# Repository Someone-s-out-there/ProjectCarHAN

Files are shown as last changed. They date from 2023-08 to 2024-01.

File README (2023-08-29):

# README

## Links

[drive](https://drive.google.com/drive/folders/1EaNdhbWhvMzq_1hj-SwhNryWp-9N5PZe?usp=sharing)

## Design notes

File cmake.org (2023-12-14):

#+AUTHOR: Sjoerd van de Wege
#+PROPERTY: header-args :tangle CMakeLists.txt
#+auto_tangle: t

* TABLE OF CONTENTS :toc:
- [[#set-cmake-version-and-project-name][set cmake version and project name]]
- [[#mcu-specifics][MCU Specifics]]
- [[#fuses][FUSES]]
- [[#toolchain][TOOLCHAIN]]
- [[#compile-flags-and-definitions][compile flags and definitions]]
  - [[#compile-defines][compile defines]]
  - [[#set--mmcu-for-both-the-compiler-and-linker][set -mmcu for both the compiler and linker]]
- [[#collect-all-source-files][collect all source files]]
  - [[#needs-to-be-turned-in-to-the-correct-directories-and-stuff][needs to be turned in to the correct directories and stuff]]
- [[#creating-the-executable-and-other-targets][creating the executable and other targets]]

* set cmake version and project name
target a relatively old version of Cmake
and set the name of the project and the outputfile to RobotCar

#+begin_src cmake

cmake_minimum_required(VERSION 3.11)
project("RobotCar")
set(PRODUCT_NAME "RobotCar")
set(CMAKE_EXPORT_COMPILE_COMMANDS 1)

#+end_src

* MCU Specifics
set the variables for the clock speed of the MCU as well as the chip used
also sets the programmer used to program the chip with avrdude

#+begin_src cmake
set(F_CPU 16000000UL) # set clock speed to 16 MHZ
set(MCU atmega328p) # set chip identity full list at (https://gcc.gnu.org/onlinedocs/gcc/AVR-Options.html)
set(PROG_TYPE xplainedmini) # set programming device

#+end_src

* FUSES 
here we're setting the fuses for the avr chip
the following calculator can be used: http://eleccelerator.com/fusecalc/fusecalc.php?chip=atmega328p
#+begin_src cmake
set(E_FUSE 0xfd)
set(H_FUSE 0xda)
set(L_FUSE 0xfd)
set(LOCK_BIT 0xff)

#+end_src

* TOOLCHAIN
sets the toolchain to be the avr-gcc toolchain
#+begin_src cmake
set(CMAKE_SYSTEM_NAME Generic)
set(CMAKE_CXX_COMPILER avr-g++)
set(CMAKE_C_COMPILER avr-gcc)
set(CMAKE_ASM_COMPILER avr-gcc)

#+end_src

* compile flags and definitions

** compile defines
#+begin_src cmake

add_definitions(
    -DF_CPU=${F_CPU}
)

#+end_src

** set -mmcu for both the compiler and linker
__attribute__ ((fallthrough)); can be used to get rid of fallthrough warnings in switch case statements
#+begin_src cmake

set(CMAKE_EXE_LINKER_FLAGS -mmcu=${MCU})

add_compile_options(
    -mmcu=${MCU} # MCU
    -std=c11 # C11 standard
    -Os # optimize
    -Wall # enable warnings
    -Wextra
    -Wundef
    -Wunused-macros
    -Wnonnull
    -Wimplicit-fallthrough
    -Wmisleading-indentation
    -Wswitch-default
    -Wunused-parameter
    -Wshadow
    -Wparentheses
    -Wpacked
    -Wpadded
    -Winline
    -pedantic
    -Wstrict-prototypes
    -Wl,--relax,--gc-sections
    -funsigned-char # a few optimizations
    -funsigned-bitfields
    -fpack-struct
    -fshort-enums
)

#+end_src

* collect all source files
collects all source files for the project
** TODO needs to be turned in to the correct directories and stuff
#+begin_src cmake

file(GLOB_RECURSE SRC_FILES CONFIGURE_DEPENDS "*c")
file(GLOB_RECURSE REMOVE_CMAKE "build/*" "extern/*" )
list(REMOVE_ITEM SRC_FILES ${REMOVE_CMAKE})
include_directories("/home/sjoerd/opt/avr/avr/include")

#+end_src

* creating the executable and other targets

#+begin_src cmake

add_executable(${PRODUCT_NAME} ${SRC_FILES})
# Rename the output to .elf as we will create multiple files
set_target_properties(${PRODUCT_NAME} PROPERTIES OUTPUT_NAME ${PRODUCT_NAME}.elf)

# Strip binary for upload
add_custom_target(strip ALL avr-strip ${PRODUCT_NAME}.elf DEPENDS ${PRODUCT_NAME})

# Transform binary into hex file, we ignore the eeprom segments in the step
add_custom_target(hex ALL avr-objcopy -R .eeprom -O ihex ${PRODUCT_NAME}.elf ${PRODUCT_NAME}.hex DEPENDS strip)
# Transform binary into hex file, this is the eeprom part (empty if you don't
# use eeprom static variables)
add_custom_target(eeprom avr-objcopy -j .eeprom  --set-section-flags=.eeprom="alloc,load"  --change-section-lma .eeprom=0 -O ihex ${PRODUCT_NAME}.elf ${PRODUCT_NAME}.eep DEPENDS strip)

# Upload the firmware with avrdude
add_custom_target(upload avrdude  -c ${PROG_TYPE} -p ${MCU} -U flash:w:${PRODUCT_NAME}.hex DEPENDS hex)

# Upload the eeprom with avrdude
# add_custom_target(upload_eeprom avrdude -c ${PROG_TYPE} -p ${MCU}  -U eeprom:w:${PRODUCT_NAME}.eep DEPENDS eeprom)

# Burn fuses
add_custom_target(fuses avrdude -c ${PROG_TYPE} -p ${MCU}  -U lfuse:w:${L_FUSE}:m -U hfuse:w:${H_FUSE}:m -U efuse:w:${E_FUSE}:m -U lock:w:${LOCK_BIT}:m )

# Clean extra files
set_directory_properties(PROPERTIES ADDITIONAL_MAKE_CLEAN_FILES "${PRODUCT_NAME}.hex;${PRODUCT_NAME}.eeprom;${PRODUCT_NAME}.lst")

#+end_src

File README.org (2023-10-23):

#+TITLE: README
#+AUTHOR: Sjoerd van de Wege
#+DESCRIPTION
#+STARTUP: showeverything
#+OPTIONS: toc:2

*  README

Here in this Repository is the code for robotcar for both the first and the second period. for the first period the car was programmed in Arduino.
now for the second period the car will be programmed in C using avr-libc with Atmel Studio 7.

** compiling
the program can be compiled using Atmel Studio 7, or using commandline utilities with the make / cmake files.
** flashing and uploading
the program can be flashed to the chip using Atmel Studio 7's programming tool.
If desired Avrdude can also be used from the commandline or using the (c)make build system
#+begin_src bash
avrdude -pm328p -c xplainedmini -U flash:w:{FILE}
#+end_src

** Links

[drive](https://drive.google.com/drive/folders/1EaNdhbWhvMzq_1hj-SwhNryWp-9N5PZe?usp=sharing)
[Atmel Studio](https://www.microchip.com/en-us/tools-resources/develop/microchip-studio)

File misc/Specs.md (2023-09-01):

# Specs

## Questions
    1. wat voor een object ontwijken / in welke omstandigheden
        a: statish behalve auto's
            op autonome mode met 4 auto zonder contact.

    2. wat is de kleur van de lijn 
        a:zwarte lijn op ondergrond van lokaal licht
    3. breedte van de lijn 
        a: isolatie tape
    4. afstand tot de voorganger 
        a: iets 30ish cm
        stop afstand.

    5. wat voor een remote controll
        a: draadloos maakt niet uit

    6  wat voor een display
        :a display o de auto 
        6.1 eenheid voor snelheid (indien geen antwoord m/s)
            a: m/s
        6.2 tijds formaat 
            a:uur minuut seconde
    7. een menu op wat? (scherm met knoppen, telefoon (bt/wifi)
        a:op auto met knoppen 

    8. reflector achter
        8.1 kleur reflector
        8.2 groote reflector
        a: ligt aan de groepjes

    9. voorkeur voor kleur led voor richting
        a: mooiste oranje, makkelijste rood

documenten als groep
voorelkaar een bijdrage factora
eurocicuits

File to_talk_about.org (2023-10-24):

#+TITLE: to talk about
#+AUTHOR: Sjoerd van de Wege
#+DESCRIPTION
#+STARTUP: showeverything

* to talk about

** review last period
*** wat ging goed
*** wat ging niet goed
** hoe verder
*** nieuwe folder structuur
*** correct gebruik git
*** 1 project to rule them all. al geconfigured met alle waarschuwingen.
*** code moet ge reviewed worden voor dat er code ge merged word naar de main of dev branch
*** structuur van project is nu in basis al gelegd.
**** de basis van het project bestaat
**** overleggen over hoe en wat qua folders en structuur voor de sensoren en actoren.

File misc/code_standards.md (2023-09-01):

# Standards

<!--toc:start-->
- [Standards](#standards)
  - [software standards](#software-standards)
    - [Source Bestanden](#source-bestanden)
      - [Source Comment](#source-comment)
      - [Headers](#headers)
      - [Macros](#macros)
    - [HEADER Bestanden](#header-bestanden)
      - [Header Comment](#header-comment)
      - [public Macros](#public-macros)
      - [public types](#public-types)
      - [public functions](#public-functions)
        - [private functions](#private-functions)
  - [hardware standards](#hardware-standards)
<!--toc:end-->

## software standards
de onderstaande file layout staat elk deel uit gewerkt in de eigen paragraaf
    File Layout(.c bestanden)
        Block comment (/*...*/)
        Headers
        Macros
        Types
        Function declarations:
            including variable names
            Group/order in Logical manner 
        Global variables
        Function definition
            same order as declaration
        main (if applicable)
    File Layout(.h bestanden)
        Block comment
        header includes
        public macros
        public types
        public functions

### Source Bestanden
#### Source Comment 
de block comment (/*...*/) bevat een beschrijving van
waar voor het bestand is. deze geeft ook aan door wie het gemaakt is,
waneer het gemaakt is. dit geldt iets minder voor de arduino ide, maar
in periode 2 is dit relevant gezien er voor alles een driver gemaakt
moet worden.

#### Headers 
de included headers gesplit in 2 secties. een sectie met
compiler provided includes (#include <...>) en een sectie voor "user"
includes(#include "..."). hiermee wordt bedoeld door ons geschreven libraries voor 
de sensoren en actoren. 

#### Macros
Macros is alles dat met #define gedefinieerd wordt. Deze macros worden
door de preprocessor vervangen door de waarde die ze dragen met een
simple text subsistutie.

### HEADER Bestanden
#### Header Comment 
de block comment (/*...*/) bevat een beschrijving van
waar voor het bestand is. deze geeft ook aan door wie het gemaakt is,
waneer het gemaakt is. dit geldt iets minder voor de arduino ide, maar
in periode 2 is dit relevant gezien er voor alles een driver gemaakt
moet worden.

#### public Macros
deze macros zijn meestal algemeene macros die ook voor andere drivers
nodig kunnen zijn. dit zijn niet alle macros door de macros te
splitsen kan je voorkomen dat je 2 macros hebt die dezelfde naam
hebben. 

#### public types 
hier eventueel de types definieeren die als parameter of als return
type zijn voor functies. 

#### public functions
de public functions dienen als toegang tot de code in de rest van het
source bestand deze zijn roepen meestal interne functies aan die niet
public zijn. dit zorgt er ook voor dat de code completion van de ide's
niet vol raakt met funcites die nooit gebruikt.

##### private functions
de functies in een C source bestand die niet vanaf een ander bestand
aangeroepen  hoeven te worden kunnen het beste gedefinieerd worden als
`static returntype func(param);` boven in het .c bestand. het static
keyword zorgt er voor dat de functie alleen beschik baar is in de .c
file.

## hardware standards
    1. alle dip chips in sockets.

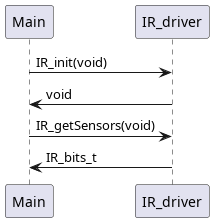
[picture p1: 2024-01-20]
uml/sensor/infrarood.png

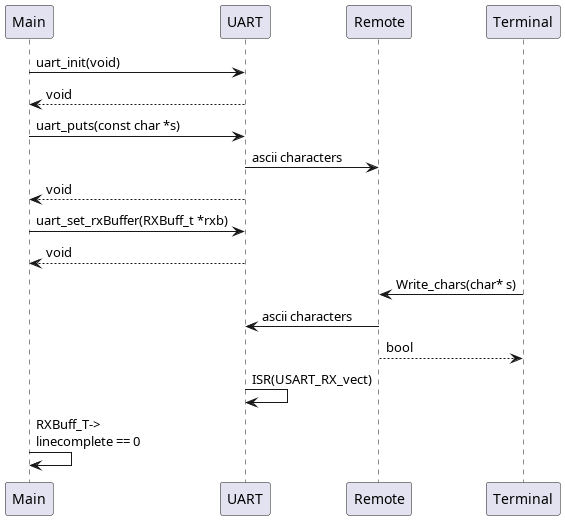
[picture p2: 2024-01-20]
uml/communication.png

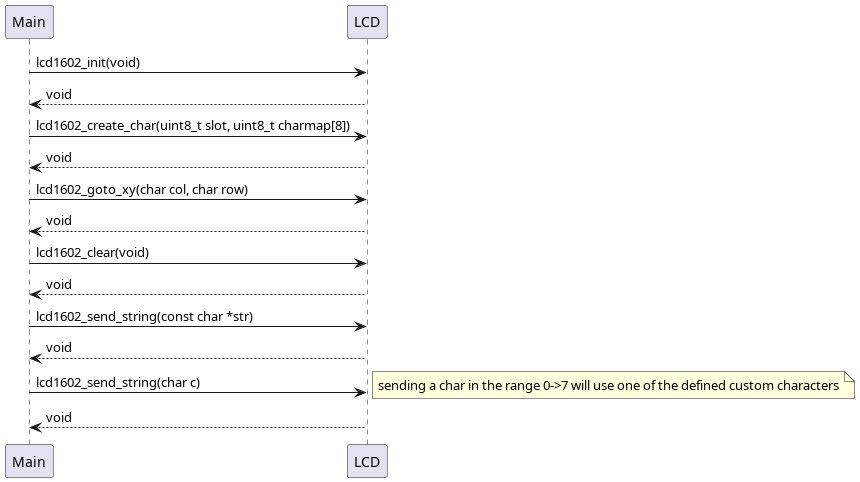
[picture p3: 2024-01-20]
uml/actor/display.png

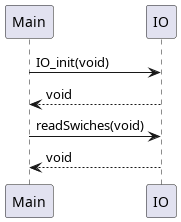
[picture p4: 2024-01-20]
uml/sensor/Switch.png

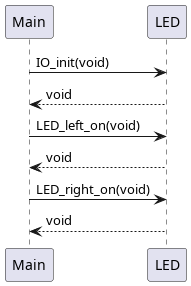
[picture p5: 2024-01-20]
uml/actor/led.png

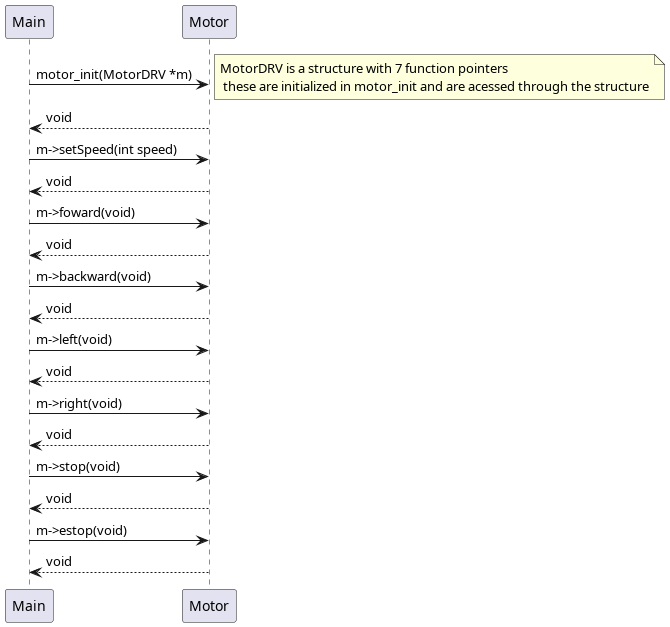
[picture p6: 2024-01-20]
uml/actor/motor.png

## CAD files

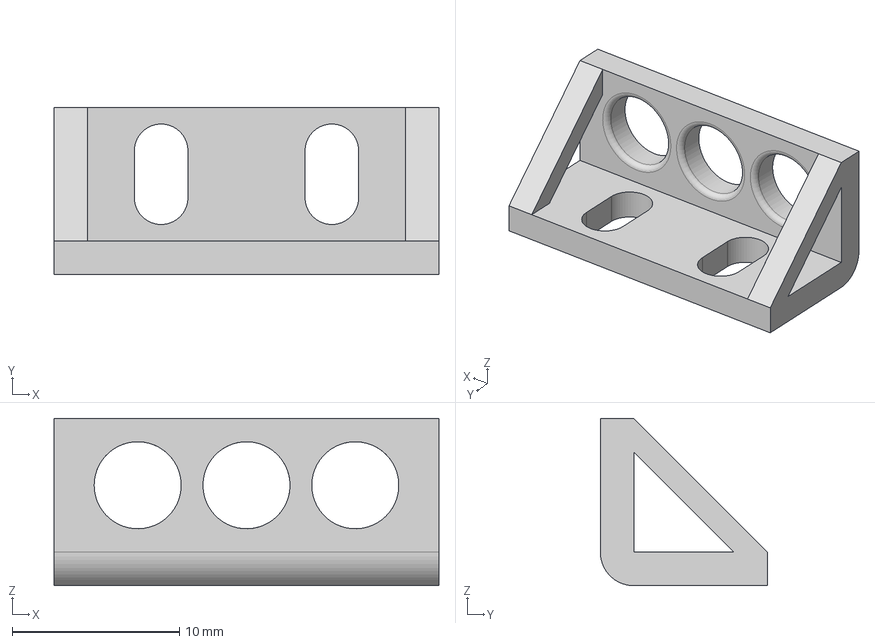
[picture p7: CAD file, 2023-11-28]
3D designs/Richtingaanwijzer/Richtingaanwijzer houder v1.1.step
23.0 x 10.0 x 10.0 mm

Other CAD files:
3D designs/Richtingaanwijzer/Richtingaanwijzer houder v1.1.stl

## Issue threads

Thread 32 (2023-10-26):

Remove front

Someone-s-out-there, 2023-10-26:

hsdqghq, 2023-11-09:
een zwenkwiel bij de hornbach als optie voor de voorwielen.
https://www.hornbach.nl/p/tarrox-zwenkwiel-tpe-o-30-mm-met-plaat/6644785/

GhostJulian, 2023-11-21:
Bonnetje van het zwenkwiel

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

GhostJulian, 2023-11-23:
Zwenkwiel is stevig gemonteerd aan de robot-auto.

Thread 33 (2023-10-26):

[FEAT] Richtingaanwijzer (anders) monteren aan robot-auto

GhostJulian, 2023-10-26:
### HUIDIGE SITUATIE
Richtingaanwijzers (2 oranje LEDS) op breadbord, in het midden van de auto.

### BETERE SITUATIE
Richtingaanwijzers aan de juiste zijde van de robot-auto monteren, mogelijk middels een 3D-print.

## NOOT: Eerst moet FEAT #70 afgerond zijn.

Closed 2023-11-30.

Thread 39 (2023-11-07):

[BUG] Fix Wiring colors

Someone-s-out-there, 2023-11-07:
**Describe the bug**
the wiring on the car is an absolute mess, there is no rhyme or reason for what color is used

**Expected behavior**
well documented color code for the wiring on the car as wel as the wires being fixed

Closed 2023-12-14.

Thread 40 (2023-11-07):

[BUG] Redesign IR sensor Bracket to be lower

Someone-s-out-there, 2023-11-07:
**Describe the bug**
the car should be raised up higher as the motor will be mounted on the bottom.

**Expected behavior**
a redesigned bracket which has roughly the same ground clearance as the current one but after the car has been lifted

Someone-s-out-there, 2023-11-07:
this is dependent on issue #47

Closed 2023-12-14.

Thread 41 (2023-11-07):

[BUG] Move ultrasoon sensors down a layer

Someone-s-out-there, 2023-11-07:
**Describe the bug**
the ultra soon sensors are mounted slightly to high and should be moved down a layer on the car to ensure that even low objects are detected

Someone-s-out-there, 2023-11-07:
this is dependent on issue #47

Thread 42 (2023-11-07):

[FEAT] Accu monitoring

GhostJulian, 2023-11-07:
### Is your feature request related to a problem? Please describe.
Monitor accu spanning, ter voorkoming dat accu volledig leeg wordt getrokken.

### Describe the solution you'd like
Zie schets op [Google drive](https://drive.google.com/drive/folders/1l317OVES7sm18uPnD8jMJrQ5r2wLMulX).
NOOT Maak eerst een aansluitschema.

**Additional context**
Wellicht is het handig om een systeem in te bouwen die er voor zorgt dat de accu ontkoppeld wordt wanneer de spanning te laag is.
Dit kan middels een relais.

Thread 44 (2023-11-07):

[FEAT] proper LCD Mount

Someone-s-out-there, 2023-11-07:
**Is your feature request related to a problem? Please describe.**
The LCD display is currently mounted on a single standoff which is quite risky as it moves around while driving

**Describe the solution you'd like**
A proper mount needs to be designed to mount the lcd better to the car

Closed 2023-12-14.

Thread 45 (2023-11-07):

aansluiten ir sensoren aan de hand van de kleurcode.

hsdqghq, 2023-11-07:

Someone-s-out-there, 2023-11-07:
for colors see issue #39

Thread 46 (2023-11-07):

[FEAT] Accu bescherming - Ompool  en kortsluitstromen

GhostJulian, 2023-11-07:
### Is your feature request related to a problem? Please describe.
De [tamiya stekker](https://www.startpage.com/av/proxy-image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) is redelijk foolproof, maar het kan nog steeds gebeuren dat de polen (+ en - ) verkeerd worden aangesloten.

### Describe the solution you'd like
Zekering  en diodes tussen accu en motordriver monteren zodat de accu en robotauto beschermt is tegen verkeerd aansluiten van accu en te grote/kortsluit stromen.

### Describe alternatives you've considered
Als alternatief kan dit integreert worden in de custom H-brug.

Someone-s-out-there, 2023-11-16:
accu protection has been made

GhostJulian, 2023-11-23:
Door gebruik te maken van de accu bescherming werkt maar 1 moter als beide het stuursignaal krijgen. Door deze module niet te gebruiken heb je dit probleem niet.

We moeten dit onderzoeken waarom dit ontstaat.

GhostJulian, 2023-11-27:
# UPDATE 27-11-2023

Tijdens het meten zag ik dat de spanning met ongeveer 1,6 volt wordt verlaagd. Dit komt door de zener diodes.
Hierdoor wordt de motor driver gevoed met de spanning tussen de 5,6 en 6,4 volt. Dit kan het probleem verklaren.

GhostJulian, 2023-12-11:
# UPDATE 07-12-2023

Accubescherming heeft nu 3 revisies.

### revisie 2
Introductie van voltage divider om spanning te kunnen meten
Deze heeft 2 normale  9v diodes. Helaas wordt de spanning zo laag dat dit problemen oplevert voor de motordriver

### revisie 3
1 diode weggehaald, accubescherming werkt nu naar behoren.

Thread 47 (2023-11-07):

[FEAT] Motors verplaatsen

GhostJulian, 2023-11-07:
### Is your feature request related to a problem? Please describe.
Op de robotauto hebben we (te) weinig ruimte, hierdoor is het lastig om onderdelen op deze robotauto te monteren.

### Describe the solution you'd like
Verplaats de motors naar de onderkant van de robotauto, hierdoor wordt de robotauto verhoogd en krijgen we meer ruimte.

Closed 2023-11-09.

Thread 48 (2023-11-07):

[BUG] Ir sensoren aansluiten aan de hand van de kleurcode. #39

hsdqghq, 2023-11-07:
De ir sensoren moeten worden aangesloten aan de hand van de kleurcode van de issue #39

Closed 2023-12-14.

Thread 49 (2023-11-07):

[FEAT] Hook up LCD display

Someone-s-out-there, 2023-11-07:
**Is your feature request related to a problem? Please describe.**
The LCD Display is currently not connected which means it cant function.

**Describe the solution you'd like**
Hook up the display

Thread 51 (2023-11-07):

[FEAT] Chaserlight module

GhostJulian, 2023-11-07:
### Is your feature request related to a problem? Please describe.
_**Could-have**_ eis is dat richtingaanwijzer knippert.
Optie toevoegen die veel lijkt op [dit](https://giphy.com/gifs/7-Lights-scheinwerferfabrik-7-lights-7lights-LRmDGDnwkeuLIh3aew).

### Describe the solution you'd like
Door een module ontwikkelen met een [solder breadboard](https://eu-browse.startpage.com/av/anon-image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) waarop een paar transistors en condensators zitten om de LED lampjes 1 voor 1 te laten branden.

**Describe alternatives you've considered**
Module kan niet direct aangesloten worden op een pin van de AVR boord omdat dit te veel stroom trekt en er een risico loopt dat deze doorbrand.
Om dit te voorkomen moet een transistor of relais te gebruiken.

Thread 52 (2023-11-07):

[FEAT] 2 nieuwe ultrasoon sensoren programeren

hsdqghq, 2023-11-07:
**Is your feature request related to a problem? Please describe.**

Doordat we maar een ultrasoon sensor gebruiken. Meet de auto sommige obstakels niet of te laat.

**Describe the solution you'd like**

We zetten er nog 2 twee ultrasoon sensoren  er op  en programmeren die in de autonoom modus.

**Describe alternatives you've considered**

geen

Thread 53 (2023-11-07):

[FEAT] I2C Display driver

Someone-s-out-there, 2023-11-07:
**Is your feature request related to a problem? Please describe.**
The Driver for the I2C display  needs to be written  based on the [libavrI2C library](https://github.com/Someone-s-out-there/libI2C)

**Describe the solution you'd like**
there needs to be a proper clear and understandable api for sending data to the display.

**Additional context**
[libavrI2C library](https://github.com/Someone-s-out-there/libI2C)

Someone-s-out-there, 2023-11-23:
extra sources [lcd_i2c_avr](https://github.com/denisgoriachev/liquid_crystal_i2c_avr)

Closed 2023-12-19.

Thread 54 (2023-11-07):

[FEAT] Draadloze remote control

GhostJulian, 2023-11-07:
### Is your feature request related to a problem? Please describe.
Huidige situatie is remote control via een USB stekker. Dit kan aangepast worden naar een draadloze aansturing.

### Describe the solution you'd like
In de eerste periode is dit besproken en hebben we gekozen om dit via Bluetooth te doen.
Hiervoor moet nog een Bluetooth module uitgekozen en gemonteerd worden op de robotauto.

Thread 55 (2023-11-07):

[FEAT] Motor Driver

Someone-s-out-there, 2023-11-07:
**Is your feature request related to a problem? Please describe.**
Program Motor driver in C in microchip studio

**Describe the solution you'd like**
full api for controlling the motors, all properly documented

Someone-s-out-there, 2023-11-28:
as per deze diagram
Gebruik designed framework

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

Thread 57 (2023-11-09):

create remaining issue

Someone-s-out-there, 2023-11-09:
- speed meting
- slave mode issues uitbreiden
- autonoom rijden uitbreiden
- IR sensor Driver
- UART DRiver

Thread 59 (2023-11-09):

[FEAT] Speed Measurement

Someone-s-out-there, 2023-11-09:
**Is your feature request related to a problem? Please describe.**
we hebben geen snelheids meting, dit was wel een vereiste van het project.

**Describe the solution you'd like**
de oplossing die we hadden bedacht is om te meeten hoe snel de auto rijd op vol pwm en op minimale pwm dat hij kan rijden en dan dat liniair te mappen naar een waarde in m/s om weer tegeven

dit zal niet altijd accuraat zijn maar is goed genoeg als basis

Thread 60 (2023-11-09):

[FEAT][draft] Slaveode Lijnvolgen

Someone-s-out-there, 2023-11-09:
**Is your feature request related to a problem? Please describe.**

**Describe the solution you'd like**
A clear and concise description of what you want to happen.

** depends on**
#driver
**Describe alternatives you've considered**
A clear and concise description of any alternative solutions or features you've considered.

**Additional context**
Add any other context or screenshots about the feature request here.

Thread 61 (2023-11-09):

[FEAT] Create IR Driver

Someone-s-out-there, 2023-11-09:
**Is your feature request related to a problem? Please describe.**
er is geen driver voor de ir sensoren

**Describe the solution you'd like**
een driver geschreven met een goede [API](https://en.wikipedia.org/wiki/API)
Deze api moet voldoen aan de gemaakte uml diagram en heeft 2 publieke functies

```c
void IR_init(void)
uint8_t IR_getSensors(void)
```
waar de data de eerste N bits zijn van de byte die gereturned word. waar N de hoeveelheid sensoren is.

**Describe alternatives you've considered**
een `getsensor` functie per sensor, maar dat levert al snel een hoop gedupliceerde code op.

**Additional context**

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

Someone-s-out-there, 2023-11-16:
fix has been merge

Closed 2023-11-16.

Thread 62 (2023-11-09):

[FEAT] Millis library

JACKAR710, 2023-11-09:
Millis library die het aantal milliseconden aan runtime returned

Someone-s-out-there, 2023-11-21:
```c
void f(){
	TCCR0A		=		(1<<WGM01);
	OCR0A		=		0xC8;
	TIMSK0 |= (1 << OCIE0A);
	TCCR0B |= (1 << CS02);

}

ISR (TIMER0_COMPA_vect) {			//TIMER 1 SECOND
	timer_count++;
	if(timer_count==156) { //DO SOMETHING EVERY SECOND
		lamp_timeout++;
		motor_timeout++;
		pir_timer++;
		led_timeout++;
		if(current_error==1){

		}

		timer_count=0;
	}
}

```
dir kan evt gebruikt worden als de juiste timer geselectteerd word en de juiste prescalar

Closed 2023-12-14.

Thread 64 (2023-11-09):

[FEAT] Accu bescherming - Overdischarge protection

GhostJulian, 2023-11-09:
### Is your feature request related to a problem? Please describe.
Ni-MH accu's kunnen kapot gaan als deze te veel ontladen wordt.

### Describe the solution you'd like
Een systeem dat rond 7 volt de accu ontkoppeld zodat de accu niet te veel ontladen wordt.

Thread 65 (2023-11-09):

[FEAT] Integreer Ultrasoon driver

Someone-s-out-there, 2023-11-09:
**Is your feature request related to a problem? Please describe.**
A clear and concise description of what the problem is. Ex. I'm always frustrated when [...]

**Describe the solution you'd like**
A clear and concise description of what you want to happen.

**depends on**
| issue content | issue nr |
|--------|--------|
| ultrasoon driver | #52  |

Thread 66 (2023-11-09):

[BUG] UART RX not working

Someone-s-out-there, 2023-11-09:
**Describe the bug**
currently the uart rx is not working as intended. it doesnt seem to receive the characters

**To Reproduce**
Steps to reproduce the behavior:
1. Flash the code in code block 1
2. open a serial term
3. type some characters and press enter
4. see no output back on the terminal

**What has already been tried**
Note down what has already been tried

**Expected behavior**
A clear and concise description of what you expected to happen.

**Screenshots**
If applicable, add screenshots to help explain your problem.

**code block one**
```c
#define F_CPU 16000000ul

#include <avr/io.h>
#include <stdint.h>
#include<util/delay.h>
#include"libUart.h"
int main(void){
  //DDRB |= (1<<DDB5)|(1<<DDB4)|(1<<DDB3)|(DDB2)|(DDB1);
  DDRB |= (0x3F);
  uart_init();
  PORTB = 0x01;
  RXBuff_t buffer;
  uart_set_rxBuffer(&buffer);
  while (1)
    {
      if(buffer.linecomplete){
	uart_puts(buffer.buffer);
	buffer.buffer_IDX = 0;
	buffer.linecomplete = 0;
      }

      _delay_ms(100);

    }
}
```

**code block 2**
```c

extern char             			uart_outbuf[UART_RX_BUFFER_SIZE + 1];
extern char            			uart_rxbuf[UART_RX_BUFFER_SIZE + 1];
extern volatile unsigned char 		uart_rx_linecomplete;
extern volatile unsigned char 		uart_rx_pos;	// end of string in rx

  ISR(USART_RX_vect)
  {
	  unsigned char c;
	  c = UDR0;				// Fetch the received byte value into the variable "ByteReceived"
	  //UDR0 = c;				// Echo back the received byte back to the computer

	  uart_rxbuf[uart_rx_pos] = c;
	  //UDR0 = c;
	  if ((c == '\n') || (uart_rx_pos > UART_RX_BUFFER_SIZE - 1)) {

		  uart_rxbuf[uart_rx_pos] = 0;
		  strcpy(uart_outbuf, uart_rxbuf);
		  uart_rx_linecomplete = 1;
		  } else {
		  uart_rx_pos++;
	  }
  }

```

Someone-s-out-there, 2023-11-09:
currently testing with just echoing the character back. by reading adn writing, interrut not working needs testing with SEI() macro

Someone-s-out-there, 2023-11-21:
needed marking of variables as volatile

Closed 2023-11-21.

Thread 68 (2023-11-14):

[FEAT] Reflector op robotoauto

GhostJulian, 2023-11-14:
### Is your feature request related to a problem? Please describe.
De klant wilt dat de robotauto aan de achterkant een reflector.
De kleur van de reflector maakt niet uit, overleg dit met de andere robotauto groepen.

### Describe the solution you'd like
Een bracket waarop de reflector gemonteerd kan worden.

GhostJulian, 2024-01-22:
Reflector zit op robot-auto

Closed 2024-01-22.

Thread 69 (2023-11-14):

[FEAT] Aan/uit schakelaar

GhostJulian, 2023-11-14:
### Is your feature request related to a problem? Please describe.
Een schakelaar monteren op de robotauto zodat de robotauto aan en of uit gezet kan worden.

### Describe the solution you'd like
Een schakelaar die de hooftstroom naar de motordriver bediend.

Closed 2023-11-30.

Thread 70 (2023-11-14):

[FEAT] Draden & weerstand(en) solderen aan LED

GhostJulian, 2023-11-14:
### Is your feature request related to a problem? Please describe.
Soldeer draden en een weerstand aan de LED zodat deze beter gemonteerd kan worden op de robotauto.

### Describe the solution you'd like
Door deze wijziging kunnen de LEDS op de juiste locatie van de robotauto gemonteerd worden.
Dit moet voor FEAT #33  uitgevoerd worden.

Closed 2023-11-21.

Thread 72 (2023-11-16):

[FEAT, ALTERNATIEF] Rubsbanden in plaats van wielen

GhostJulian, 2023-11-16:
### Is your feature request related to a problem? Please describe.
Tijdens de tussentijdse oplevering viel het mij op dat de robotauto's erg veel op elkaar lijken.
We kunnen onze robotauto uniek maken door gebruik te maken van rubsbanden.
Dit brengt wel wat complexiteit met zich mee doordat de rubsbanden en sprocket goed op elkaar passen en de rubsbanden moeten goed opgespannen zijn anders kan deze vastlopen en of er vanaf vallen.

### Describe the solution you'd like
In plaats van gebuik te maken van oplossing #32  door deze toe te passen.
Op het internet zijn erg veel verschillende designs beschikaar, een van deze kunnen we gebruiken, wat weer scheelt in ontwikkeltijd.
Deze oplossing lijkt mij het makkelijkst om toe te passen op onze robotauto: [Mini tank -FPV-Rover](https://www.thingiverse.com/thing:2478547).

### Describe alternatives you've considered
Hieronder staan enkele alternatieven die wellicht ook kunnen:
[T-34 tanktrack - Printables](https://www.printables.com/model/99893-rc-tank-t-34-ps-231-1-part-1-tracks)
[ESP-32 cam - Printables](https://www.printables.com/model/612126-track-tank-vehicle-with-esp32-cam)
[WALL-E tracks - Printables](https://www.printables.com/model/408363-wall-e)
[Tank Tracks Desktop Toy - Thingiverse](https://www.thingiverse.com/thing:4340407)
[Modular Tank Tracks - Thingiverse](https://www.thingiverse.com/thing:726259)
[speed tank tracks bad ass - Thingiverse](https://www.thingiverse.com/thing:2662530)
[Mini robot tank V2 - Cults3d](https://cults3d.com/en/3d-model/various/mini-robot-tank-v2)

GhostJulian, 2023-11-21:
TIjdens het overleg op 21-11-2023 is besloten om deze feature niet uit te voeren doordat dit te veel onzekerheid geeft aan dit project.

Closed 2023-11-21.

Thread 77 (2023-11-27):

Bouwplan maken

Someone-s-out-there, 2023-11-27:
Make. Van een bouwplan

Voor 7 december, dit is de laatste projecturen die ingeroosterd zijn voor de inleverdatum

1 globale lijn, en dan in zoomen op een onderwerp per keer

Presentatie visueel te volgen van achter in.

GhostJulian, 2023-12-11:
Op zondag 10-12-2023 is dit ingeleverd.

Closed 2023-12-11.

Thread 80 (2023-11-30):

[FEAT] Voltage regulator PCB voor Microcontroller

GhostJulian, 2023-11-30:
### Is your feature request related to a problem? Please describe.
4 * 1,2 AA batterijen in serie hebben een te hoge voltage voor de AVR microcontroller.

**Describe the solution you'd like**
Een printplaat met een voltage regulator zodat we niet de microcontroller opblazen.

GhostJulian, 2023-11-30:
Op 30 november 2023 om 14:15 afgerond.

Closed 2023-11-30.

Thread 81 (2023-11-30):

[FEAT] Montage IR printplaat met potmeters aan robotauto

GhostJulian, 2023-11-30:
### Is your feature request related to a problem? Please describe.
IR fine-tune module hangt nu los te bungelen bij de robot-auto, dit ziet er rommelig uit en zit in de weg.

### Describe the solution you'd like?
Montage of 3D print zodat de IR fine-tune module vast zit aan de Robot-auto.

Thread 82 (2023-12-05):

[FEAT] Rework uart

Someone-s-out-there, 2023-12-05:
# design
- the reworked lib can take either a rxbuffer struct
- or a char* to a buffer and a length,
- or can be told to use an internal buffer(fifo design) (Preferred use)

# inplementation
[fifo buffer](https://gist.github.com/ryankurte/61f95dc71133561ed055ff62b33585f8) needs some adapting
char* and length can be stored internally

Closed 2023-12-11.

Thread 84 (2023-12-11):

[BUG] IR Sensors schuiven over de grond

GhostJulian, 2023-12-11:
### Describe the bug
De montage van de IR sensors zit te laag waardoor ze over de grond heen schuren, dit kan later problemen veroorzaken.

### Possible fix
De gaten uithollen zodat de afstand tussen grond en LEDs ingesteld kunnen worden.

### Expected behavior
Sensors mogen niet over de grond heen schuiven, hierdoor kunnen we problemen krijgen.

Closed 2023-12-19.

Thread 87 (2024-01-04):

missing void param in function definition for ultrasonic sensor

Someone-s-out-there, 2024-01-04:
missing void parameter in function def

https://github.com/Someone-s-out-there/ProjectCarHAN/blob/ea9666c64b6912ef658bb8e1fe53f83ed7614c57/RobotCar/ultrasonic/Ultrasonic.h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
https://github.com/Someone-s-out-there/ProjectCarHAN/blob/ea9666c64b6912ef658bb8e1fe53f83ed7614c57/RobotCar/ultrasonic/Ultrasonic.h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

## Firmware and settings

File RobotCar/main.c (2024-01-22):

/*
 * RobotCar.c
 *
 * Created: 10/23/2023 7:16:03 PM
 * Authors : Sjoerd van de Wege & Julian Janssen &
 *			 Ayman el Barakat & Joep Spaanjaars
 */
#include <avr/eeprom.h>
#include <avr/interrupt.h>
#include <avr/io.h>
#include <stdbool.h>
#include <stdint.h>
#include <util/delay.h>

#include "DriveModes/autonomous.h"
#include "DriveModes/modes.h"
#include "DriveModes/remote.h"
#include "EEPROM/userTime.h"
#include "Functions/Appinfo.h"
#include "Functions/Buttons/mode_select.h"
#include "Functions/Millis/Millis.h"
#include "Functions/Pinmap.h"
#include "Functions/Voltage_monitoring/Voltage_monitoring.h"
#include "Motor/motor.h"
#include "Uart/Uart.h"
#include "i2c/display.h"
#include "i2c/lcd.h"
#include "ultrasonic/Ultrasonic.h"

extern MotorDRV motor;
modes_t current_mode = REMOTE;
uint8_t last_button_state = 0;

#define GET_BUTTON_STATE() !(PINC & (1 << PINC0));

int main(void) {
    IO_init();
    uart_init();
    millis_init();
    ultrasonic_init();
    motor_init(&motor);
    lcd1602_init();
    _delay_ms(1);

    lcd1602_clear();
    lcd1602_goto_xy(0, 0);

    updateUserTime();
    last_button_state = GET_BUTTON_STATE();

    while (1) {
        // get button input
        uint8_t current_button_state = GET_BUTTON_STATE();

        if (current_button_state != last_button_state) {
            last_button_state = current_button_state;

            if (current_button_state == 1) {
                current_mode++;
                if (current_mode > AUTONOMOUS) {
                    current_mode = STOPPED;
                }
            }
        }

        //        updateUserTime();
        displayBattery();
        displayMode(current_mode);
        switch (current_mode) {
            case STOPPED:
                break;
            case REMOTE:
                RemoteControl_Mode();
                break;
            case SLAVE:
                break;
            case AUTONOMOUS:
                break;
        }
    }
}

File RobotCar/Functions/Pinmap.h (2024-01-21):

/*
 * Pinmap.h
 *
 * Created: 9-11-2023 10:39:29
 *  Author: jspaa
 */

#ifndef PINMAP_H_
#define PINMAP_H_

#include <avr/io.h>

typedef enum { INPUT = 0, OUTPUT = 1, INPUT_PULLUP = 1 } dataDirection_t;

// Initialize Pins
#define IR1 PIND2
#define IR2 PIND3
#define IR3 PIND4
#define IR4 PIND5

#define US_TRIG PIND6
#define US1_ECHO PIND7

#define H_LEFT PINB0
#define PWM_LEFT PINB1
#define PWM_RIGHT PINB2
#define H_RIGHT PINB3

#define LED_LEFT PINB4
#define LED_RIGHT PINB5

#define SW1 PINC0
#define US2_ECHO PINC1
#define US3_ECHO PINC2

// Analog input (PC3 nog niet geïnitialiseerd)

// Initialize Registers
void IO_init(void);

#endif /* PINMAP_H_ */

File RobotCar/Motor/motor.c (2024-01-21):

#include "motor.h"

#include <avr/io.h>
#include <stdint.h>
#include <util/delay.h>

MotorDRV motor;

static uint16_t currentspeed = 512;

void motor_init(MotorDRV *m) {
    // Link functions
    m->setSpeed = &setSpeed;
    m->foward = &foward;
    m->backward = &backward;
    m->left = &left;
    m->right = &right;
    m->stop = stop;
    m->estop = &estop;

    // Configure PB0, PB1, PB2, PB3, PB4 and PB5 as output
    DDRB |= (1 << PORTB5) | (1 << PORTB4) | (1 << PORTB3) | (1 << PORTB2) |
            (1 << PORTB1) | (1 << PORTB0);

    /*
    Set PB0 and PB3 LOW
    PB 1 and PB2 will be controlled by  timer1
    */
    PORTB &= ~(1 << PORTB3) & ~(1 << PORTB0);
    /*
    | NOTE Timer 1 is 16 bits large!
    |
    |	Enable Fast-PWM mode 10 bits
    | BOTTOM -> TOP = 0 -> 1023
    | COM1A1 & COM1B1 = enable compare OC1A & OC1B
    \*/
    TCCR1A |= (1 << WGM12) | (1 << WGM11) | (1 << WGM10);
    // TCCR1B |= (1<<CS11) | (1<<CS10);

    /*
    TOP = (F_CPU / (F_PWM * N)) - 1
    = (16MHz / (1953.1z * 8)) - 1

    prescaler 256 = 61.029hz
    prescaler 64 = 244.2hz = 1023
    prescaler 8 = 1953.1hz

    Set the prescaler on 8, so the frequenty is about 1953 hz.
    */
    ICR1 = 1023;

    TCCR1A |= (1 << COM1A1) | (1 << COM1B1);

    /*
    Set starting compare value
    */
    OCR1A = currentspeed;
    OCR1B = currentspeed;
}

void setSpeed(uint16_t speed) { currentspeed = speed; }

void foward(void) {
    // Turn off the direction lights
    PORTB &= ~((1 << PORTB5) | (1 << PORTB4));

    // Set PB0 and PB3 to HIGH
    PORTB |= (1 << PORTB3) | (1 << PORTB0);

    OCR1A = currentspeed;
    OCR1B = currentspeed;

    // turn on the timer1
    TCCR1B |= (1 << CS11) | (1 << CS10);
}

void backward(void) {
    // Turn off the direction lights
    PORTB &= ~((1 << PORTB5) | (1 << PORTB4));

    // Set PB0 and PB3 LOW
    PORTB &= ~(1 << PORTB3) & ~(1 << PORTB0);

    OCR1A = currentspeed;
    OCR1B = currentspeed;

    // turn on the timer1
    TCCR1B |= (1 << CS11) | (1 << CS10);
}

void left(void) {
    // Set PB0 to HIGH and PB3 to LOW
    PORTB |= (1 << PORTB0) | (1 << PORTB4);
    PORTB &= ~(1 << PORTB3);

    OCR1A = currentspeed;
    OCR1B = currentspeed;

    // turn on the timer1
    TCCR1B |= (1 << CS11) | (1 << CS10);
}

void right(void) {
    // Set PB0 to HIGH and PB3 to LOW
    PORTB |= (1 << PORTB3) | (1 << PORTB5);
    PORTB &= ~(1 << PORTB0);

    OCR1A = currentspeed;
    OCR1B = currentspeed;

    // turn on the timer1
    TCCR1B |= (1 << CS11) | (1 << CS10);
}

void stop(void) {
    OCR1A = 0;
    OCR1B = 0;

    // Turn off the direction lights
    PORTB &= ~((1 << PORTB5) | (1 << PORTB4));

    // turn off the timer1
    TCCR1B &= ~(1 << CS11) & ~(0 << CS10);
}

void estop(void) {
    OCR1A = 0;
    OCR1B = 0;

    // Turn off the direction lights
    PORTB &= ~((1 << PORTB5) | (1 << PORTB4));

    // turn off the timer1
    TCCR1B &= ~(1 << CS11) & ~(1 << CS10);
}

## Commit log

2023-09-25 Testcode motors
    Test code voor het besturen van de motors op de robotcar.
2023-09-26 MotorsTest & Remote control
    Programma om motors te testen via de Serial Monitor
2023-09-26 folder "motor_codes" toegevoegd
    folder "motor_codes" toegevoegd, zodat de codes folder niet onoverzichtelijk door de motor codes.
2023-09-29 added velocity change and stop funciton. this also runs a command until told to stop
2023-09-29 commented unused pin contorls
2023-10-03 Motorcontrol struct updated
    motorcontrol_stuct.ino formatted, motorconttorl_struct_test folder verwijderd
2023-10-03 motorcontrol formatted, updated forlder
    motorcontrol_struct.ino document formatted, testfolder removed.
    motorcontrol_struct folder moved to motor codes folder.
2023-10-03 motorcontol V3 added
    added motorcontol.h
2023-10-03 concept motorcontrol
    Voorbeeld met de motorcontol.h document.
    programma is getest op robotauto
2023-10-04 added a slow stop as default stop. added estop - slowstop has become default action, - e stop needs new char check in the switch
2023-10-04 formatting + added estop in switch
2023-10-05 Made cpp file for motor_controls class, added Estop code
    - Motor_controls klasse verplaatst naar Motor_controls.cpp
    - functies toegevoegd aan Motor_controls.h file
    - Code aanpassing van Sjoerd toegegevoegd.
    - Code is getest op voertuig
2023-10-05 Us sensor met gemiddelde
    Berekent gemiddelde uit 4 metingen
2023-10-05 added simple recursive filter to the ultrasonic sensor
2023-10-05 display code v2
    Battery added
2023-10-06 richtingslichten toegevoegd aan motorcontrols
2023-10-06 Tested ultrasonic_test_avg
    getest, kleine fout verbeterd, code opgeschoond
    Doordat er geen delay zit met het ophalen van de gegevens, komt het voor dat de distance 0 is.
2023-10-06 moved ultrasonic codes to 'ultrasonic_codes'
    For cleanup code dir
2023-10-06 module for ultrasoon code merged with AVG filter
    Module voor Ultrasoon code
2023-10-13 fixed trigger and echo pin
2023-10-13 set to one switch
2023-10-23 Cmake (#26)
    * added cmake.org to generate CMakeLists.txt
    * added remote-control code and sketch for the intergrated car code
    * rebase onto main changes
    * Kleine programmeer fout fix
    * [UNTESTED] autonomous code
    * [TESTED] autonomouse mode
    Robot-car kan nog steeds vastlopen bij zijkanten.
    * formatted
    * commentaar toegevoegd in Autonomous.ino, overbodige code verwijderd, dubble code verwijderd
    * fixed merge conflicts
    * fixed trigger and echo pin
    * Speed added
    speed added and updateUserTime() is commented to save the eeprom
    * merged the separate projects into one sketch to properly intergrate it all
    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
2023-11-09 Added: - Millis function - Appinfo
2023-11-14 added uart lib trying to fix the sending of data from the laptop to the AVR
    [Uart.c]
2023-11-14 misc cmake changes and main to test uart
2023-11-14 removed uart from wrong branch'
    [Uart.c, main.c]
2023-11-15 Fixed Uart RX, storage var wasn't marked as volatile
    [Uart.c, main.c]
2023-11-16 changing uart to use structure again
2023-11-16 added documentation and set the IR sensor pins as input instead of output
2023-11-16 added documentation to Uart driver
2023-11-23 Millis function working.
2023-11-23 Millis function fixed and working
2023-11-23 Buttons alles gaat fout
    21 errors
    [Pinmap.h, main.c]
2023-11-27 3D designs van de richtingaanwijzer
    [Richtingaanwijzer houder.step, Richtingaanwijzer houder.stl]
2023-11-27 Schuine balken dikker gemaakt
    [Richtingaanwijzer houder.step, Richtingaanwijzer houder.stl]
2023-11-27 Richtingaanwijzer geüpdated
    Fout in 3D design gecorrigeerd
    [Richtingaanwijzer houder v1.1.step, Richtingaanwijzer houder v1.1.stl, Richtingaanwijzer houder.step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]
2023-11-28 added motor driver frame work, needs implementation
2023-12-05 uart.h added
2023-12-05 motor driver skeleton
2023-12-05 fixed main.c merge debacle
    [main.c]
2023-12-05 updated uart to be able to use fifo
2023-12-05 modified uart, Now memsetting the buffer is easy, te buffer can also be switched out
2023-12-06 Succesful build 0 Errors 0 Warnings Het idee is dat er na 2 keer op de knop te drukken pin PB4 een output geeft, maar het werkt niet.
    [Pinmap.c, Pinmap.h, main.c]
2023-12-07 Working button cycle
2023-12-07 working button
2023-12-14 ADC configured and tested
    Range between 0 and 1023
2023-12-14 Conversion to voltage added
    Tested on robot-auto
    ======= TEST RESULTS =======
    Battery voltage: 7,7 volt
    Voltage on divider: 4,01 volt
    AVR measure (uint16_t): 398
    AVR measure (REAL): 3,98 volt
2023-12-14 Removed code to test voltage monitoring
2023-12-15 Update Voltage_monitoring.c
    Moved ISR(ADC_vect) to the bottom of file
2023-12-15 Update Voltage_monitoring.c
    Added doxgen text
2024-01-20 merged motor code and made main working
2024-01-22 ultrasonic sensors pre test
2024-01-23 batteryPercentage 8 naar 32 bits
